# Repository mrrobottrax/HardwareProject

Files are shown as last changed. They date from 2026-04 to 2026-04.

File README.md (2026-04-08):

# Bomb Defusal Game

Project Members:

Ethan Schledewitz-Edwards 100908840

Andrew Hoult 100866035

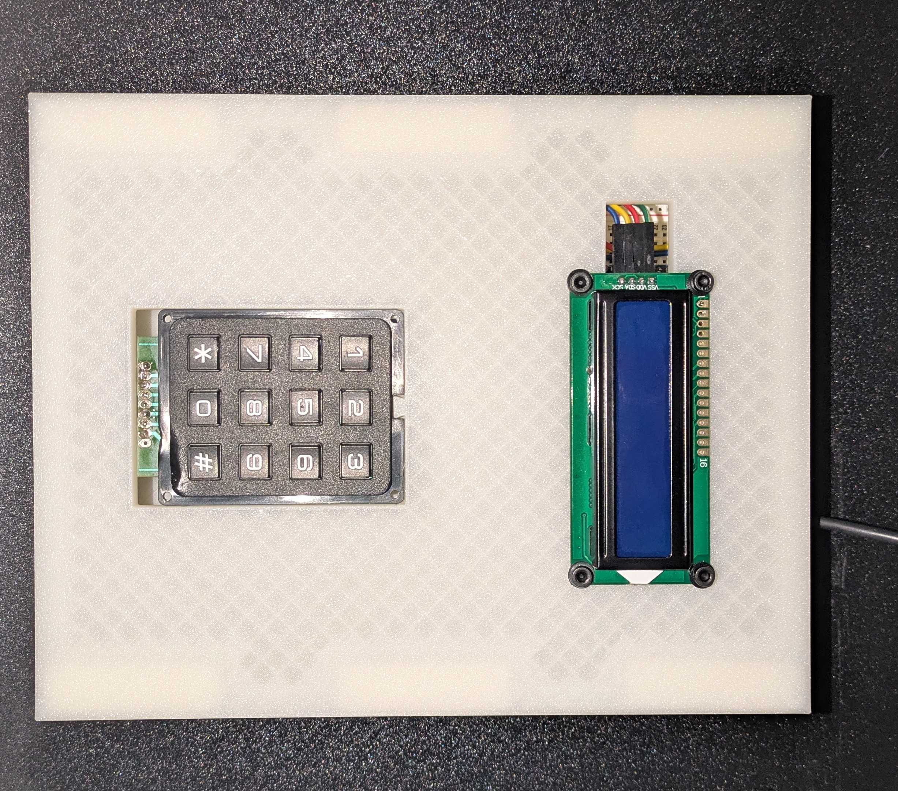
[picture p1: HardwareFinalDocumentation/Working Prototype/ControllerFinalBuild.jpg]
Final build


## Repository Structure

Documentation is stored in HardwareFinalDocumentation/, source code is stored in SourceCode/.

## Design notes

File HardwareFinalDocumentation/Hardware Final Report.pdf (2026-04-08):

# Developing a Tangible User Interface for Entertainment

Andrew Hoult
Faculty of Business and Information Technology Ontario Tech University
Oshawa, ON, Canada
andrew.hoult@ontariotechu.net

Ethan Schledewitz-Edwards
Faculty of Business and Information Technology Ontario Tech University
Oshawa, ON, Canada
ethan.schledewitzedwars@ontariotechu.net

Abstract—Designing and developing an intuitive Tangible User Interface (TUI) involves many careful considerations. Intuitive operation, comfort in layout, immersive-ness, and responsiveness must be factored into the iterative process. The purpose of this device is to create a “bomb-defusal” controller that leverages physical and design affordances to satisfy these pillars of design. Initial paper prototyping focused on ergonomics and identifiable iconography associated with bombs in media. Later prototypes focused on implementing one component of the controller incrementally. User testing of a prototype reveals that incorporating design and physical affordances into TUI’s results in intuitive systems.
Index Terms—Physical User Interface, Tactile, Tangible User Interface, Intuitive, Affordances
I. Introduction

For a Tangible User Interface (TUI) to be successful, it must be intuitive to operate, comfortable to engage with, immersive, and respond as the user expects. These core pillars are essential when designing immersive gaming hardware that relies on physical interaction as its primary mechanic. This report details the development of a physical “bomb-defusal” controller inspired by the digital game Keep Talking and Nobody Explodes. The project explores how design affordances can be leveraged to create a fun experience that a user can complete without instruction. To solve this problem, the device implements tactile inputs through a matrix keypad and an accelerometer to map digital game logic onto familiar physical interactions. Users are tasked with defusing the bomb by playing through separate game modules using the sensors implemented in the device. [1], [2]

II. Materials and Methods

A. Materials

The core logic of this device is controlled by an ESP32 micro-controller. The ESP32 was chosen for its low cost, processing speed, and compact size. User input is captured via two primary interfaces: a 3x3 matrix keypad and a 3-axis I2C MPU6050 accelerometer. The keypad was chosen for its versatility across multiple games and its association with the design of bombs in media. The accelerometer was integrated to introduce unconventional, motion-based mechanics not typically found in representations of bomb defusal.

Visual feedback is rendered via an HD44780 compatible 1602 LCD over I2C, while audio is output from a DFPlayer Mini communicating with the ESP32 over UART to drive a speaker. The chassis of this device was modeled in Fusion 360 and constructed using 3D-printed PLA, resulting in a lightweight and durable enclosure.

B. Methods

The hardware was developed through an iterative process. Initial cardboard prototyping was used to determine the optimal size of the chassis and the placement of the sensors and actuators. This was followed by a functional prototype where the physical components were validated on a breadboard individually. The final iteration involved migrating the components from a temporary breadboard to the printed chassis, ensuring the controller could withstand being tilted and handled during the accelerometer-based game.

III. Results

The final prototype successfully integrated all hardware modules into a cohesive TUI. User testing confirmed that the ESP32 maintained stable communication with the I2C accelerometer and the UART-driven MP3 speaker. However, testing revealed that the LCD display was highly unstable. When powered over USB, the display’s internal controller would occasionally enter an unrecoverable state until power cycled. A 100μf capacitor was added as an attempt to mitigate this phenomenon, with inconclusive results. Additionally, input latency between the matrix keypad and the display was found during user testing. This latency is attributed to the software and was rectified in future iterations.
User testing focused on intuitiveness and the responsiveness of the keypad interface. Quantitative data from the SUS and NASA-TLX surveys (see Table I and Table II) highlight the device’s ease of use, high task success, and low participant stress, validating the keypad’s design affordances. Unfortunately, due to timing, testing could not be performed with the components housed within the chassis. Additionally, the accelerometer was not utilized in the game used for the test.

IV. Takeaways

The development of this tangible “bomb-defusal” controller confirms that integrating design affordances, such as a keypad, significantly reduced the cognitive load required for immersive gameplay without instruction. This is supported by a mean SUS score of 78.3, indicating “High” usability. However, the identified LCD instability and input latency resulted in some users reporting perceivable inconsistencies in the device. For this device to be successful, these inconsistencies must be alleviated to create an immersive experience. Going forward, the core pillars of intuitive operation, comfort in layout, immersive-ness, and responsiveness must be applied to the rest of the components as they are integrated.

TABLE I
System Usability Scale (SUS) survey responses (N=9).
User | Q1 | Q2 | Q3 | Q4 | Q5 | Q6 | Q7 | Q8 | Q9 | Q10
1 | 4 | 2 | 2 | 1 | 5 | 2 | 5 | 2 | 3 | 2
2 | 3 | 3 | 4 | 2 | 4 | 3 | 4 | 2 | 4 | 2
3 | 3 | 1 | 3 | 1 | 4 | 4 | 5 | 2 | 5 | 1
4 | 2 | 1 | 5 | 1 | 4 | 4 | 5 | 2 | 5 | 2
5 | 4 | 1 | 5 | 1 | 3 | 1 | 5 | 1 | 4 | 2
6 | 5 | 2 | 4 | 3 | 5 | 1 | 5 | 2 | 3 | 2
7 | 4 | 2 | 4 | 1 | 5 | 1 | 4 | 2 | 5 | 3
8 | 4 | 3 | 3 | 1 | 3 | 2 | 4 | 2 | 3 | 1
9 | 3 | 1 | 4 | 1 | 5 | 2 | 5 | 2 | 5 | 1

TABLE II
NASA-TLX workload dimensions measured across 9 participants.
User | Physi-cal | Hur-ried | Suc-cess | Hard Work | Stressed
1 | 1 | 2 | 9 | 3 | 1
2 | 2 | 2 | 7 | 3 | 2
3 | 1 | 4 | 7 | 5 | 3
4 | 1 | 1 | 9 | 6 | 2
5 | 4 | 3 | 10 | 3 | 2
6 | 2 | 8 | 9 | 10 | 1
7 | 1 | 3 | 9 | 1 | 1
8 | 4 | 4 | 8 | 6 | 2
9 | 1 | 1 | 9 | 5 | 2

References

[1] Steel Crate Games, “Keep Talking and Nobody Explodes.” Oct. 2015.
[2] E. Shamilov, N. Gavish, H. Krisher, and E. Horesh, “Tangible user interface,” Engineering Psychology and Cognitive Ergonomics – EPCE 2018, vol. 10906. in Lecture Notes in Computer Science, vol. 10906. Springer, Cham, Switzerland, pp. 393–402, 2018. doi: 10.1007/978-3-319-91122-9_38. (https://doi.org/10.1007/978-3-319-91122-9_38)

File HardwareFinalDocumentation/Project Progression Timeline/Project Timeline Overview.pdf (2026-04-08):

### Project Timeline Overview

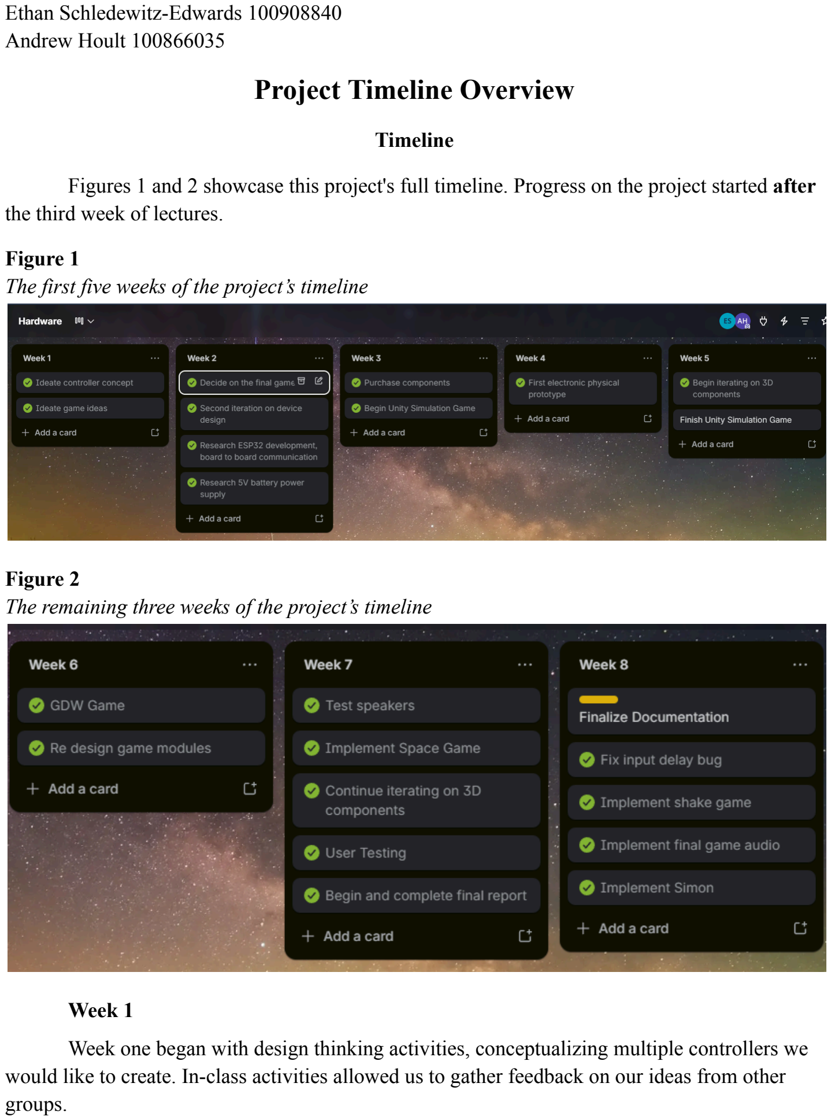
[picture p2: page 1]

Ethan Schledewitz-Edwards 100908840 Andrew Hoult 100866035

Timeline

Figures 1 and 2 showcase this project's full timeline. Progress on the project started after the third week of lectures.

Figure 1
The first five weeks of the project’s timeline

Figure 2
The remaining three weeks of the project’s timeline

Week 1
Week one began with design thinking activities, conceptualizing multiple controllers we would like to create. In-class activities allowed us to gather feedback on our ideas from other groups.

Week 2
Based on our findings in week one, the final concept for our controller was selected and iterated on. The group we consulted the week prior recommended that we include unconventional input methods into our controller to create an element of surprise. Based on the finalized concept, research was conducted to determine which electronic components and materials we needed to purchase to build the controller.
Week 3
Based on the research from the previous week, electronic components were purchased from Amazon. Additionally, a Unity-based simulation of the project began development. The simulation would have allowed us to test the flow of game modules and how they would behave. Week 4
Unfortunately, due to a heavy course load, the Unity prototype was canceled as we deemed it unfeasible. However, the parts ordered the previous week were arriving. Using these components, the initial physical electronic prototyping began using a breadboard.
Week 5
As previously mentioned, the digital Unity prototype had been canceled in week 4. However, in week 5, 3D components were beginning to be iterated on using Fusion 360. These designs focused on housing for the individual components. This week included housing for the Keypad, LCD, and breadboard.

Week 6

Week six mostly focused on improving our GDW game before Milestone 3. However, programming for the controller prototype began, LCD issues were rectified, and an LCD interface was created.

Week 7

The LCD issues are somewhat resolved, the first game is complete, all components are integrated and functioning, and an API for each component has been created. User testing is conducted in the game lab. The final report is written and completed using the data gathered from the user testing.

Week 8

Minor bugs were fixed, and all game modules and code were completed before Tuesday (LevelUp Convention). Finally, the project was submitted on Wednesday morning.

Work Breakdown

Andrew: Assembled electronics, 3D printed parts and iterated design, programmed microcontroller games.

Ethan: I worked on the concept, design, canceled Unity Prototype, some 3D component designs, and user testing of the project along with Andrew. I also handled all of the technical documentation.

Overall, we feel that the workload was evenly distributed between us, 50% each.

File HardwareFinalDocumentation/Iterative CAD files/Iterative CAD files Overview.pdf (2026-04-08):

Ethan Schledewitz-Edwards 100908840 Andrew Hoult 100866035

### Iterative CAD files Overview

Video Demonstration

Exploded View Video: https://youtu.be/3uYHuE0vSzA

Electronic Schematics

Multiple changes to the scope of the project were made for the electronic components. Initially, the components were selected to facilitate 5 unique games, with dedicated sensors and actuators for most. Since the project focused primarily on game design, its scope was initially quite large. However, as the final deadline approached, technical feasibility was assessed, and costs were factored in; two final sensors and actuators were chosen. Figure 1 illustrates the initial schematic used to construct the final prototype.
The first sensor included in the final prototype is the 3x3 matrix keypad. The keypad was chosen for numerous reasons. First, the keypad allows the concept of the controller to meet the users' expectations of a “bomb-defusal” game. As discussed in the final report, bombs in popular media often depict bombs with a keypad on the front. By using a keypad, the device could leverage established design conventions to communicate the purpose of the device more easily. Next, the keypad was favoured for the number of buttons on the keypad, which supports a wide variety of games.
The second sensor included in the final prototype of this controller was an accelerometer. Because this project focuses on “unconventional” gameplay not commonly associated with bomb-defusal, an accelerometer was selected to surprise the user. The accelerometer is used in the “shake” game, where the user must shake the controller vigorously to increase a progress bar. Next, the first actuator chosen for the controller was the I2C LCD. For the same reason mentioned for the matrix keypad, the LCD aids the controller in bridging the user's mental gap between bombs in media and this controller. The LCD display also facilitates multiple games, making it a versatile choice for this project.
Lastly, the second actuator chosen for this project is the speaker. The speaker allows the controller to play a variety of sounds conveying its state to the user. Sounds are played through the speaker from a micro SD bus, and range from conventional ominous bomb ticking sounds to more unfamiliar sounds. For reasons previously mentioned, combining both conventional bomb iconography with unconventional new elements unique to this controller creates a sense of surprise in the user.

Figure 1
An electronic schematic made in Tinkercad

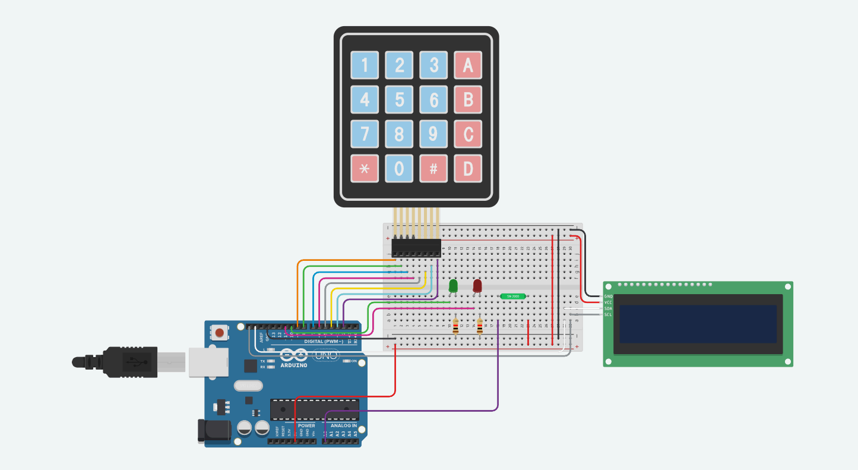
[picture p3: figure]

Note. This schematic is missing an accelerometer and a speaker. These omissions were made because the scope of the project had not been finalized.

3D Assembly

Blueprints/Drawings

The following two drawings were made using Fusion 360's drafting tools. Custom housing for each component of this controller was designed and iterated on separately. Each iteration brought the housing closer to the required dimensions of each component. For example, iterations changed the size of screw holes.

Figure 2 is the blueprint for the Lid of the controller. On the lid is the housing for the LCD display and the Keyboard. Once both housing designs were finalized, the two components were attached to the Lid of the device.

Figure 2
A technical drawing of the Lid

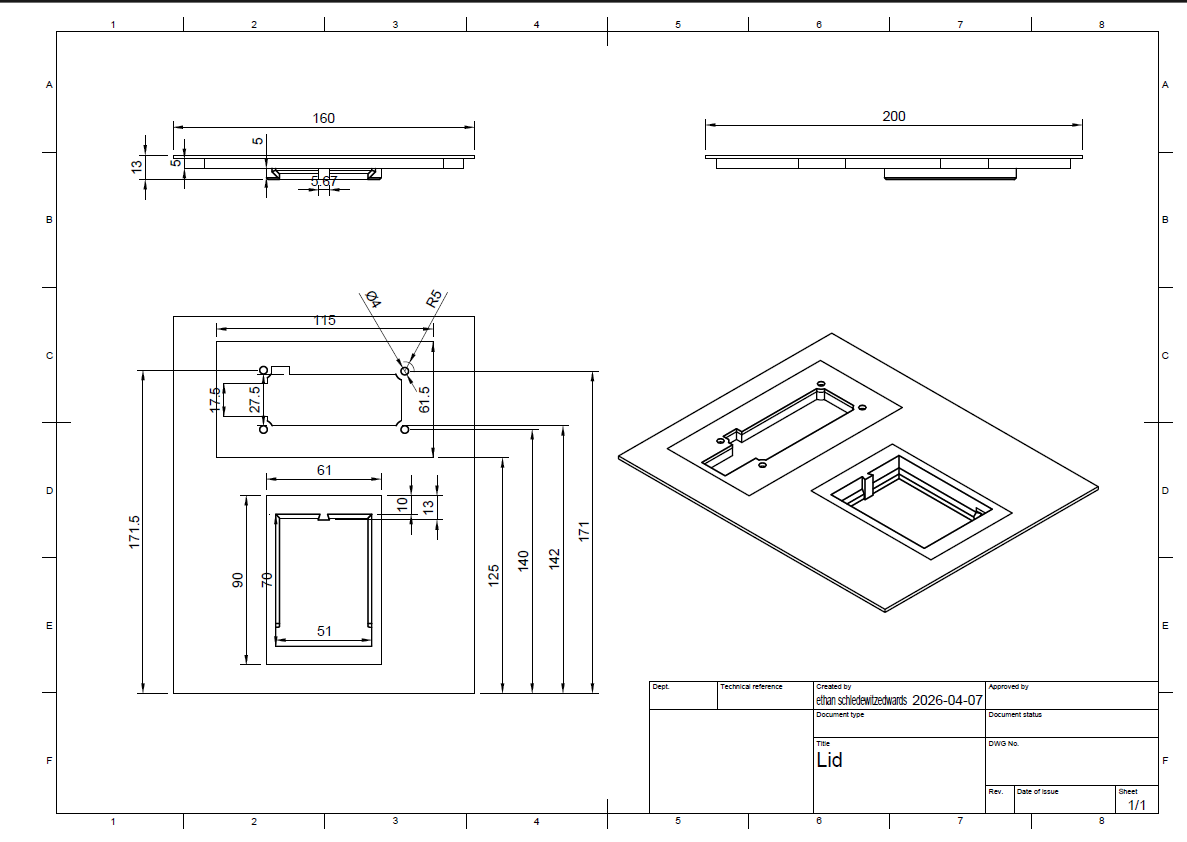
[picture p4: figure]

Figure 3 is the blueprint for the Chassis of the controller. The Chassis includes six magnets to fasten it to the bottom of the Lid. The chassis features a custom mount for the breadboard, ESP32, and speaker. The three custom mounts were iterated on separately and added to the Chassis once they were finalized.

Figure 3
A technical drawing of the Chassis

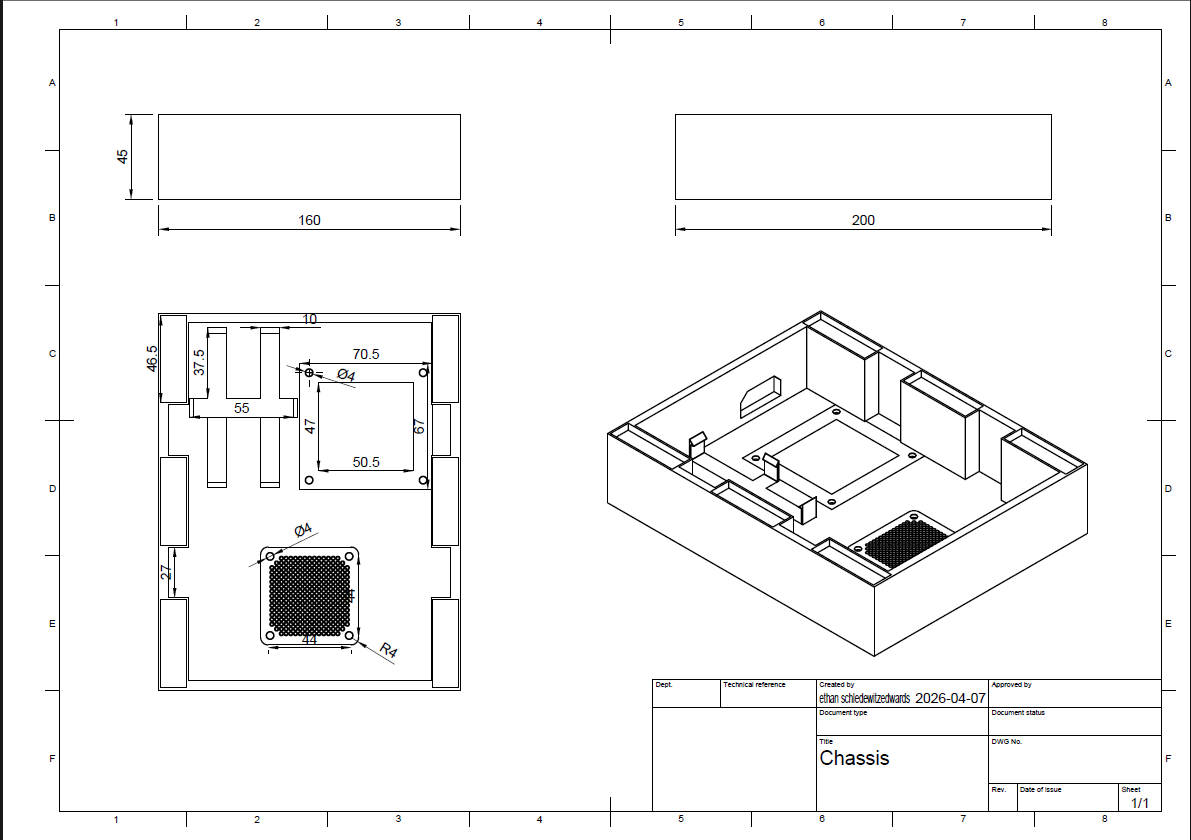
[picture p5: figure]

Exploded View

Figure 3 showcases the exploded view of our controller. The image was captured from our “Controller Exploded View” video, which was rendered using Fusion 360’s animation tools.

Figure 3
A screenshot of the Exploded View from the rendered video

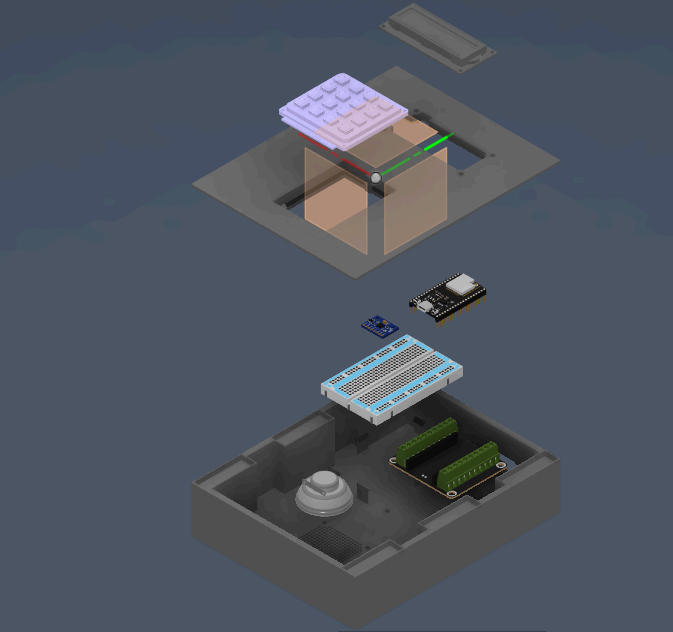
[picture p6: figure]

Approach on Iteration

To ensure that all the electronic components and wires fit neatly within our controller's exterior, careful measurements were taken for each part using calipers. Each measurement also detailed recommended clearance for wiring, ensuring the shell could contain absolutely everything. For example, Figure 4 illustrates the measurements taken for the 3x3 Matrix Keypad with a suggested clearance for wiring to run 3mm below the component.

Figure 4
Measurements for the keypad, taken using calipers

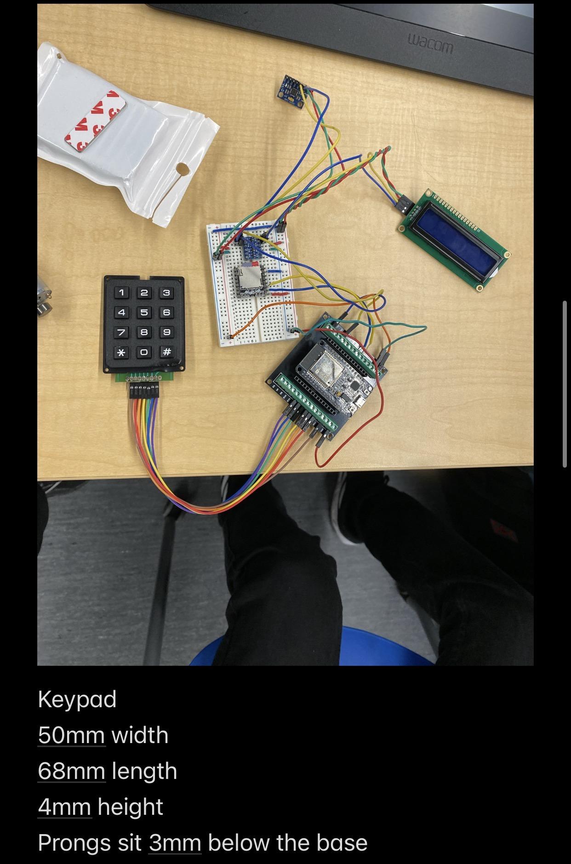
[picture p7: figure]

Using these measurements, individual housing for each component was prototyped using Fusion 360. For instance, Figure 5 showcases multiple iterations of housing designed specifically for the LCD screen. Figure 6 highlights multiple iterations for the Keypad and Speaker housing.

Figure 5
Iterations on the housing for the LCD screen

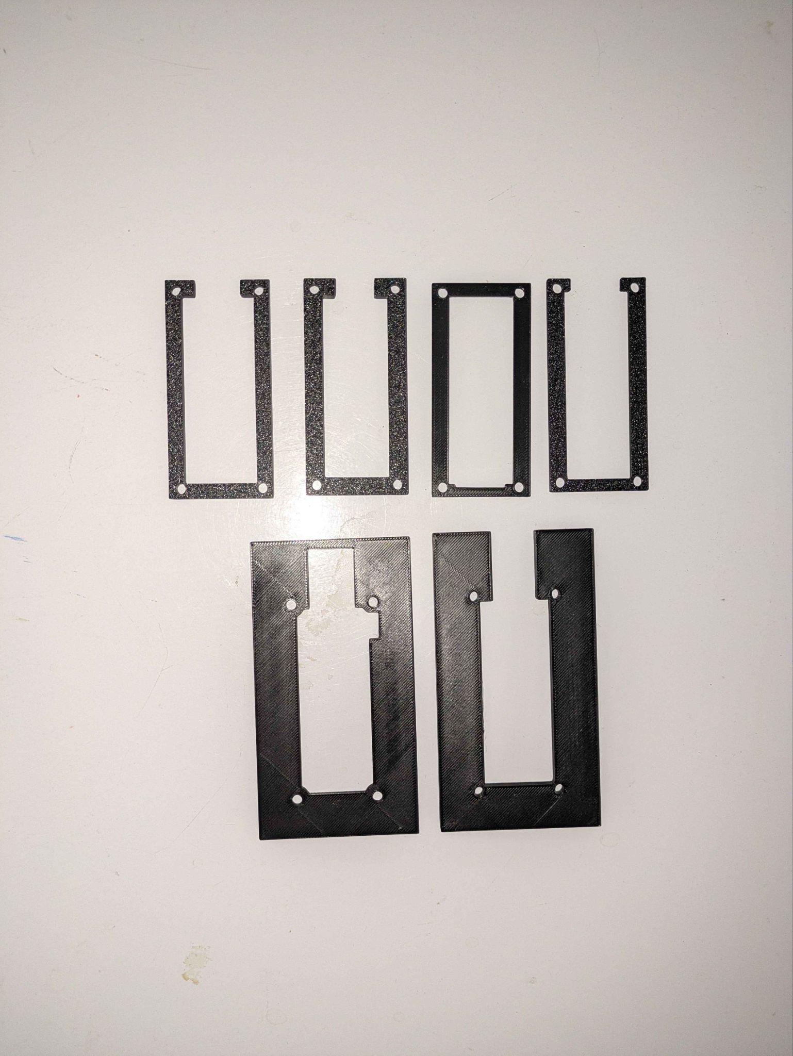
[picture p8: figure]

Figure 6
Iterations on the housing for the keypad, speaker, and breadboard

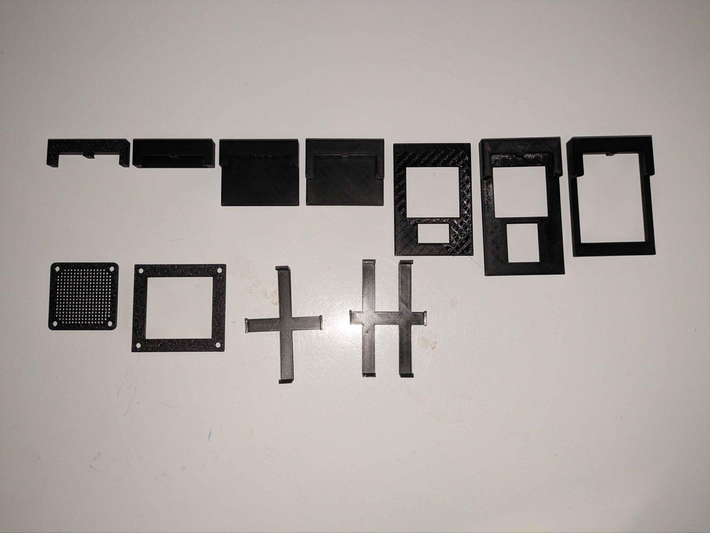
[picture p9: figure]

Note. The top row of prototypes is solely for the Keypad, the bottom row features two iterations for the speaker housing, and three iterations for the breadboard housing.
The design of the housing for each component was iterated on extensively, ensuring it fit each component optimally. Once each individual component had housing designed for it, all components were combined into the design for the final Chassis and Lid of this controller prototype. Much like the housing for the individual components, both the Chassis and Lid underwent multiple iterations to ensure everything fit nicely.

Bill of Materials

After the design of the Lid and Chassis of the controller was finalized, the Bill of Materials visualized in Figure 7 was created using Fusion 360’s drawing tools.

Figure 7
The final Bill of Materials

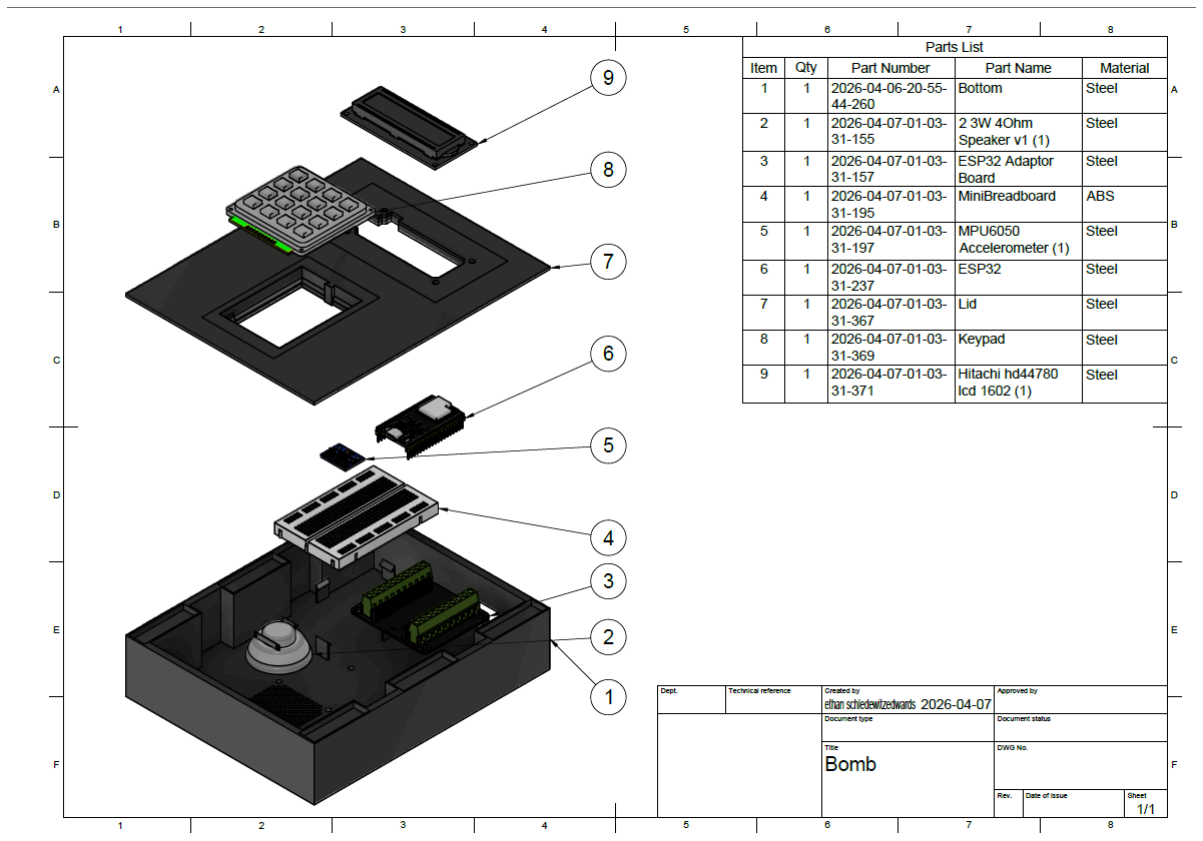
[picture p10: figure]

Note. Some of the models used to represent the electronic components are incorrect and were used as approximations for the exploded view and bill of materials. The incorrect components are the matrix keypad and LCD screen.

References

[LCD]
https://grabcad.com/library/hitachi-hd44780-lcd-1602-1

[ESP32]
https://grabcad.com/library/esp32-devkit-32u-with-external-antenna-and-3-types-of-adapter-boar ds-1 (https://grabcad.com/library/esp32-devkit-32u-with-external-antenna-and-3-types-of-adapter-boards-1)

[Breadboard]

https://grabcad.com/library/minibreadboard-2

[Accelerometer]
https://grabcad.com/library/mpu6050-accelerometer-module-2

[Speaker]
https://grabcad.com/library/3w-4ohm-speaker-1

[Keypad]
https://grabcad.com/library/4x4-button-keypad-matrix

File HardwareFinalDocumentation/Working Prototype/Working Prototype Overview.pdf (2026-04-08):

Ethan Schledewitz-Edwards 100908840 Andrew Hoult 100866035

### Working Prototype Overview

Video Demonstration

Working Prototype Video Demonstration 1: https://youtu.be/9d6GbXNmM6Y Working Prototype Video Demonstration 2: https://youtu.be/H2iKPrMXN8s

Electronics Integration

The two videos provided above outline the integration of the electronics in this controller prototype comprehensively. Figures 1 and 2 visualize the controller showcased in the videos.

Figure 1
An image of the exterior of the controller prototype

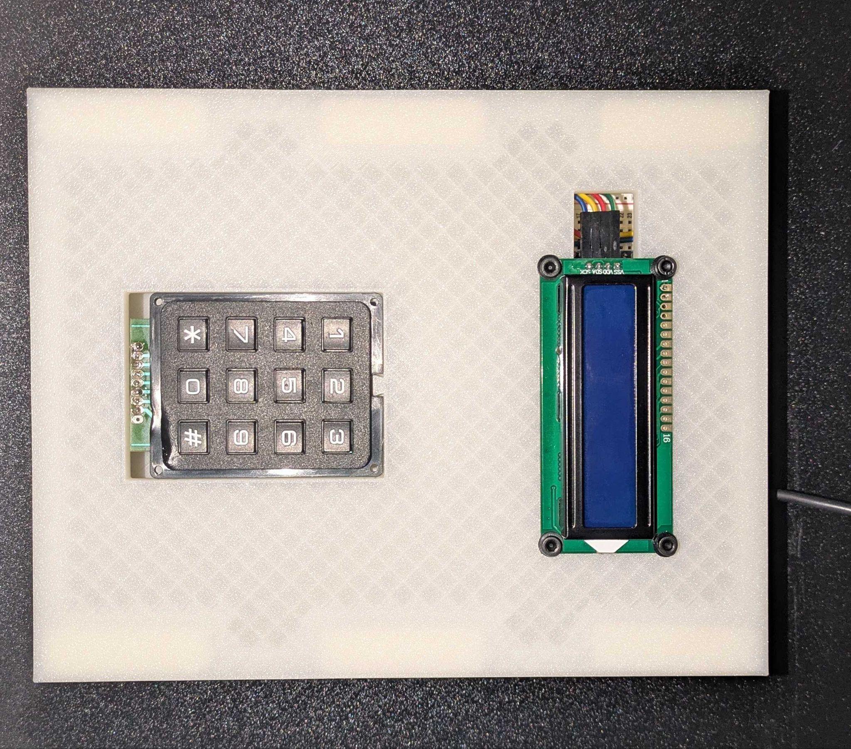
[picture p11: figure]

Figure 2
An image of the interior of the controller prototype

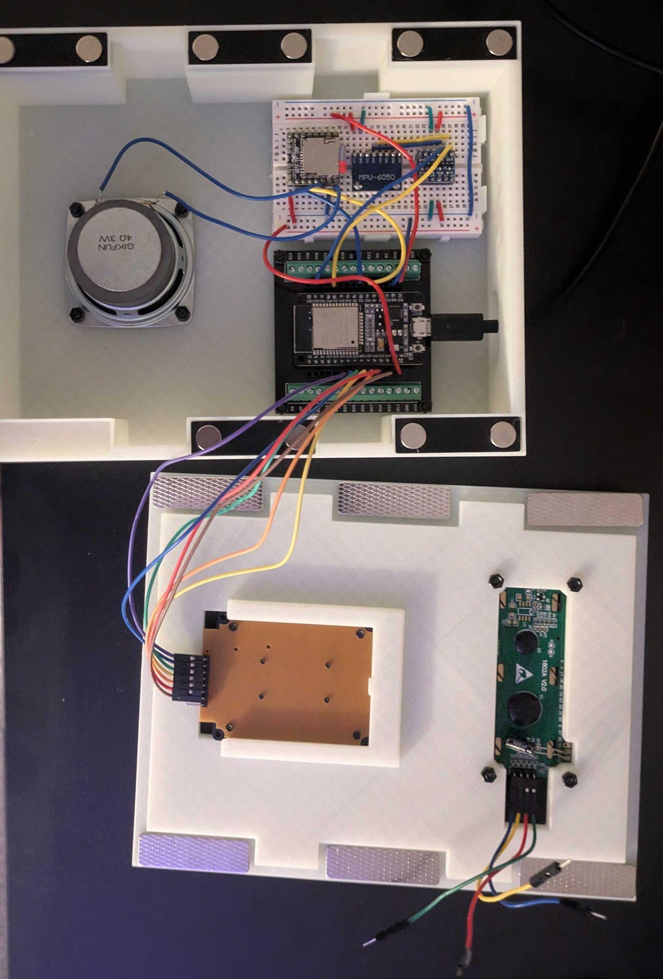
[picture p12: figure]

Bill of Materials

After the design of the Lid and Chassis of the controller was finalized, the Bill of Materials visualized in Figure 3 was created using Fusion 360’s drawing tools.

Figure 3
The final Bill of Materials

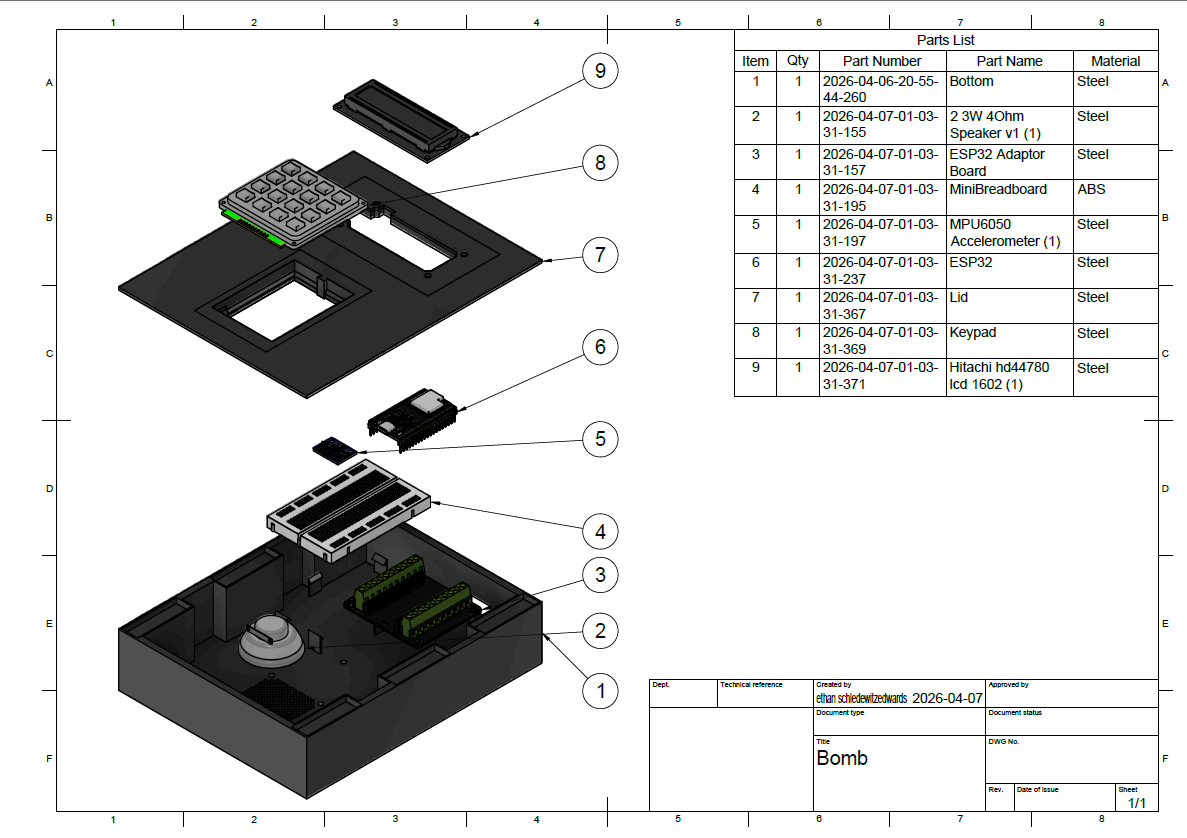
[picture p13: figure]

Note. Some of the models used to represent the electronic components are incorrect and were used as approximations for the exploded view and bill of materials. The incorrect components are the matrix keypad and LCD screen.

References

[LCD]
https://grabcad.com/library/hitachi-hd44780-lcd-1602-1

[ESP32]
https://grabcad.com/library/esp32-devkit-32u-with-external-antenna-and-3-types-of-adapter-boar ds-1 (https://grabcad.com/library/esp32-devkit-32u-with-external-antenna-and-3-types-of-adapter-boards-1)

[Breadboard]
https://grabcad.com/library/minibreadboard-2

[Accelerometer]
https://grabcad.com/library/mpu6050-accelerometer-module-2

[Speaker]
https://grabcad.com/library/3w-4ohm-speaker-1

[Keypad]
https://grabcad.com/library/4x4-button-keypad-matrix

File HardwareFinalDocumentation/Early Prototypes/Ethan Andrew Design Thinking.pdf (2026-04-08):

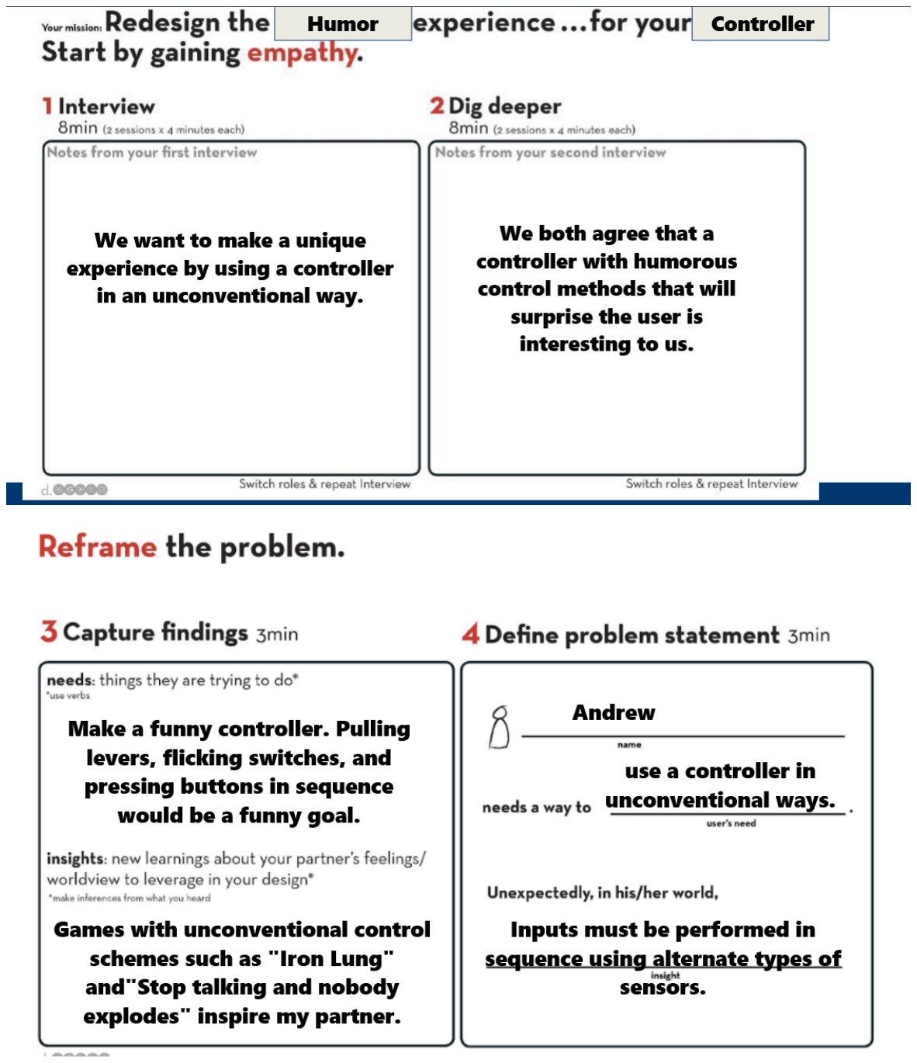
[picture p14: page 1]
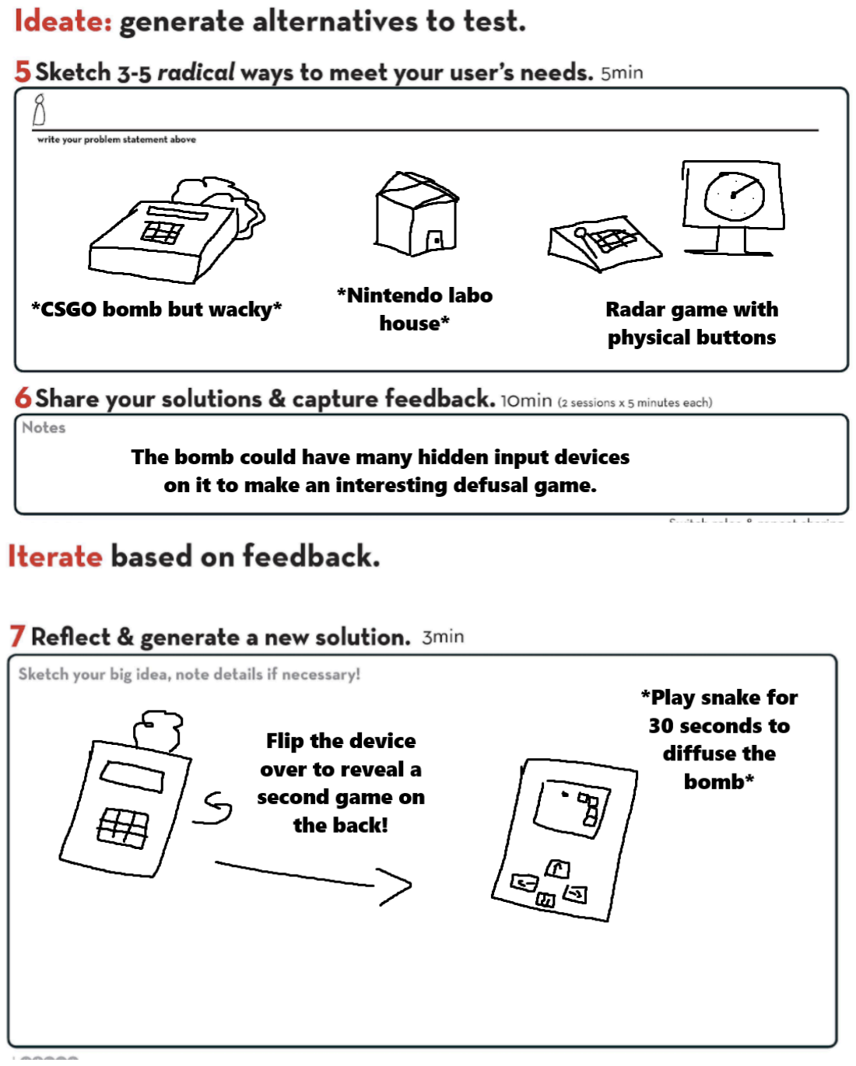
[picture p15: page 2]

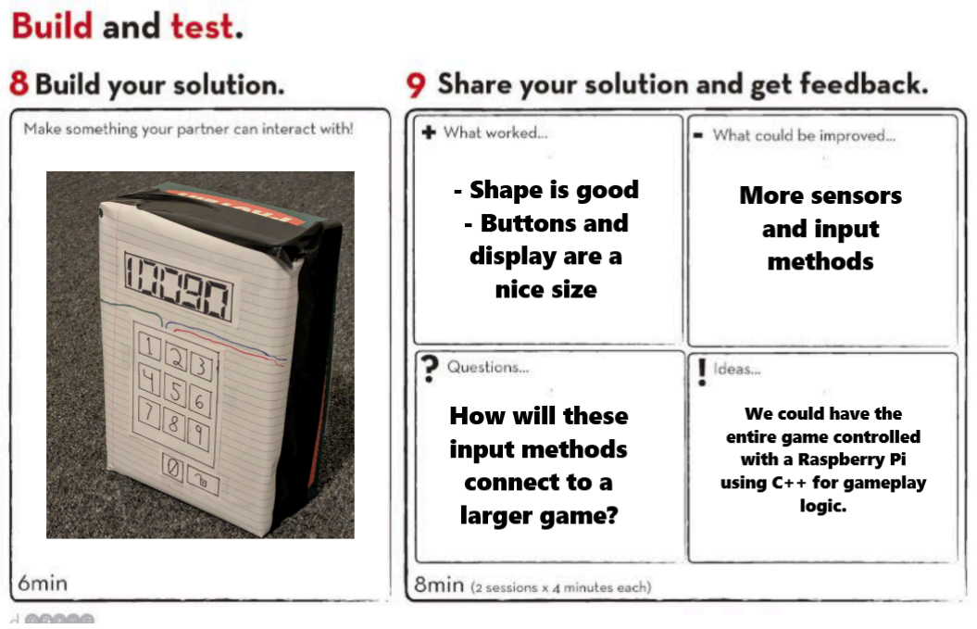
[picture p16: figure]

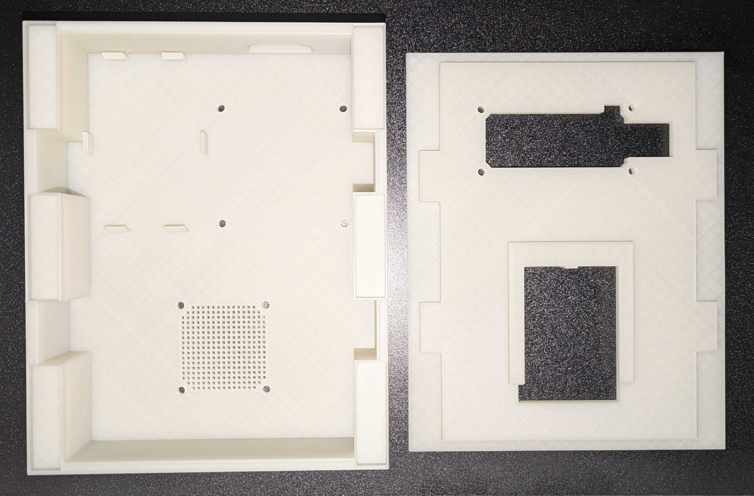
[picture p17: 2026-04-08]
HardwareFinalDocumentation/Iterative CAD files/FinalyChasisAndLid.jpg

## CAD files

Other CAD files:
HardwareFinalDocumentation/Early Prototypes/HardwareController.blend
HardwareFinalDocumentation/FInalControllerPrototype.f3z

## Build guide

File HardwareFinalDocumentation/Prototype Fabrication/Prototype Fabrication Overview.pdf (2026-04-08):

Ethan Schledewitz-Edwards 100908840 Andrew Hoult 100866035

### Prototype Fabrication Overview

Video Demonstration

Lid Slicer Video: https://youtu.be/1y99QEnaCtU
Chassis Slicer Video: https://youtu.be/KqiIBcV46DE Timelapse of Lid print: https://youtu.be/cRQq90OvXEM Timelapse of Chassis print: https://youtu.be/emaSV7wItIM

Materials Chosen

Generic PLA was chosen for 3D printing the Lid and chassis of our controller. The print was done using a Bambu Lab P1S.

Printing Time

Printing the Lid took two hours and nine minutes, as shown in Figure 1. Next, printing the chassis took five hours and twenty minutes, as shown in Figure 2. In total, printing both housing pieces for our controller took seven hours and twenty-nine minutes.

Figure 1
Time to print the lid of the device

Figure 2
Time to print the chassis of the device

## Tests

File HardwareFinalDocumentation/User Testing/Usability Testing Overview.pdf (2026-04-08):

Ethan Schledewitz-Edwards 100908840 Andrew Hoult 100866035

### User Testing Overview

Introduction

The user testing conducted for our controller prototype involved nine participants. Each participant was questioned on their background, SUS, and NASA TLX. Since this project is a group of two, eight total participants were required. The user testing was conducted in the Game Lab and only included one game. The sensor and actuator used for the test were the 3x3 matrix keypad and the I2C LCD. Due to the project running behind schedule due to other academic responsibilities, only one game could be tested using the sensor (the keypad) and actuator (the LCD).
Key takeaways

The final report included with this project fully details our “key takeaways” from the user testing. To summarize these points:

- The prototype controller was simple to use
- Users found the prototype comfortable to interact with the
- Users did not require much assistance to operate the controller prototype
- Users reported inconsistencies with the controller.

A spreadsheet containing the results from the user testing is included with this document. Based on observations, a majority of the friction experienced by the participants stemmed from the LCD screen inexplicably disconnecting temporarily. This discrepancy was lessened by integrating a capacitor into the wiring in response. Despite these inconsistencies, users found the experience intuitive.

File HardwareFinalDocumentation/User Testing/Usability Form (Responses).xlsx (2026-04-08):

Timestamp | What is your gender? | What is your age? | What is your background | Do you have any experience with similar systems? | I think that I would like to use this system frequently. | I found the system unnecessarily complex. | I thought the system was easy to use. | I think that I would need the support of a technical person to be able to use this system. | I found the various functions in this system were well integrated. | I thought there was too much inconsistency in this system | I would imagine that most people would learn to use this system very quickly. | I found the system very cumbersome to use. | I felt very confident using the system. | I needed to learn a lot of things before I could get going with this system. | How physically demanding was the task? | How hurried or rushed was the pace of the task? | How successful were you in accomplishing what you were asked to do? | How hard did you have to work to achieve your level of performance? | How insecure, discourage, irritated, stressed, and annoyed were you?
2026-04-02 19:09 | Male | 24 | GDIW | I’ve used num pad before | 4 | 2 | 2 | 1 | 5 | 2 | 5 | 2 | 3 | 2 | 1 | 2 | 9 | 3 | 1
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

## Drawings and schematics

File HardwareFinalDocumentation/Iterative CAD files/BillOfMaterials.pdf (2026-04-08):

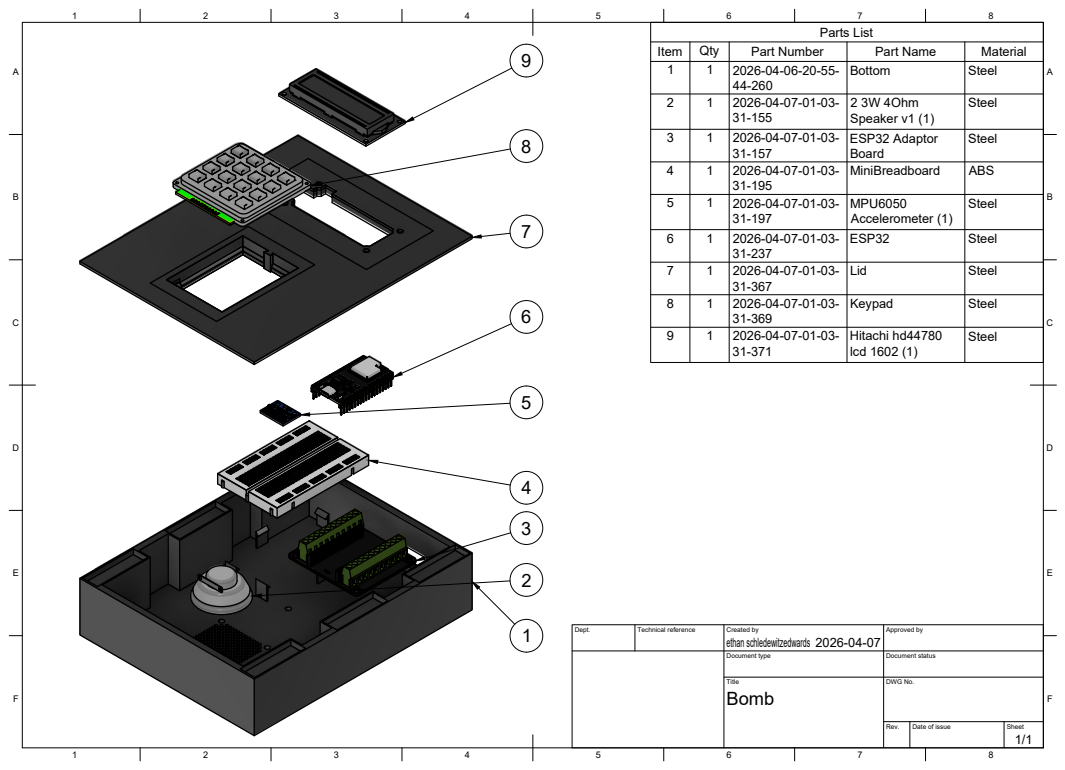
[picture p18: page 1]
8 BCDEF; ABCDEF; Title; DWG No.; Rev.; Date of issue; Sheet; Parts List; Steel 213456789

Item | Qty 1 | 2026-04-06-20-55-Part Number | Part Name | Material 1
1 | 2026-04-07-01-03-44-260 | Bottom | Steel 2

1 | 2026-04-07-01-03-31-155 | 2 3W 4Ohm Speaker v1 (1) | Steel 3

1 | 2026-04-07-01-03-31-157 | ESP32 Adaptor Board | Steel 4

1 | 2026-04-07-01-03-31-195 | MiniBreadboard | ABS 5

1 | 2026-04-07-01-03-31-197 | MPU6050 Accelerometer (1) | Steel 6

1 | 2026-04-07-01-03-31-237 | ESP32 | Steel 7

1 | 2026-04-07-01-03-31-367 | Lid | Steel 8

1 | 2026-04-07-01-03-31-369 | Keypad | Steel 9

31-371 | Hitachi hd44780 lcd 1602 (1)

Dept. | Technical reference | Created by ethan schledewitzedwards 2026-04-07 | Approved by

Document type | Document status

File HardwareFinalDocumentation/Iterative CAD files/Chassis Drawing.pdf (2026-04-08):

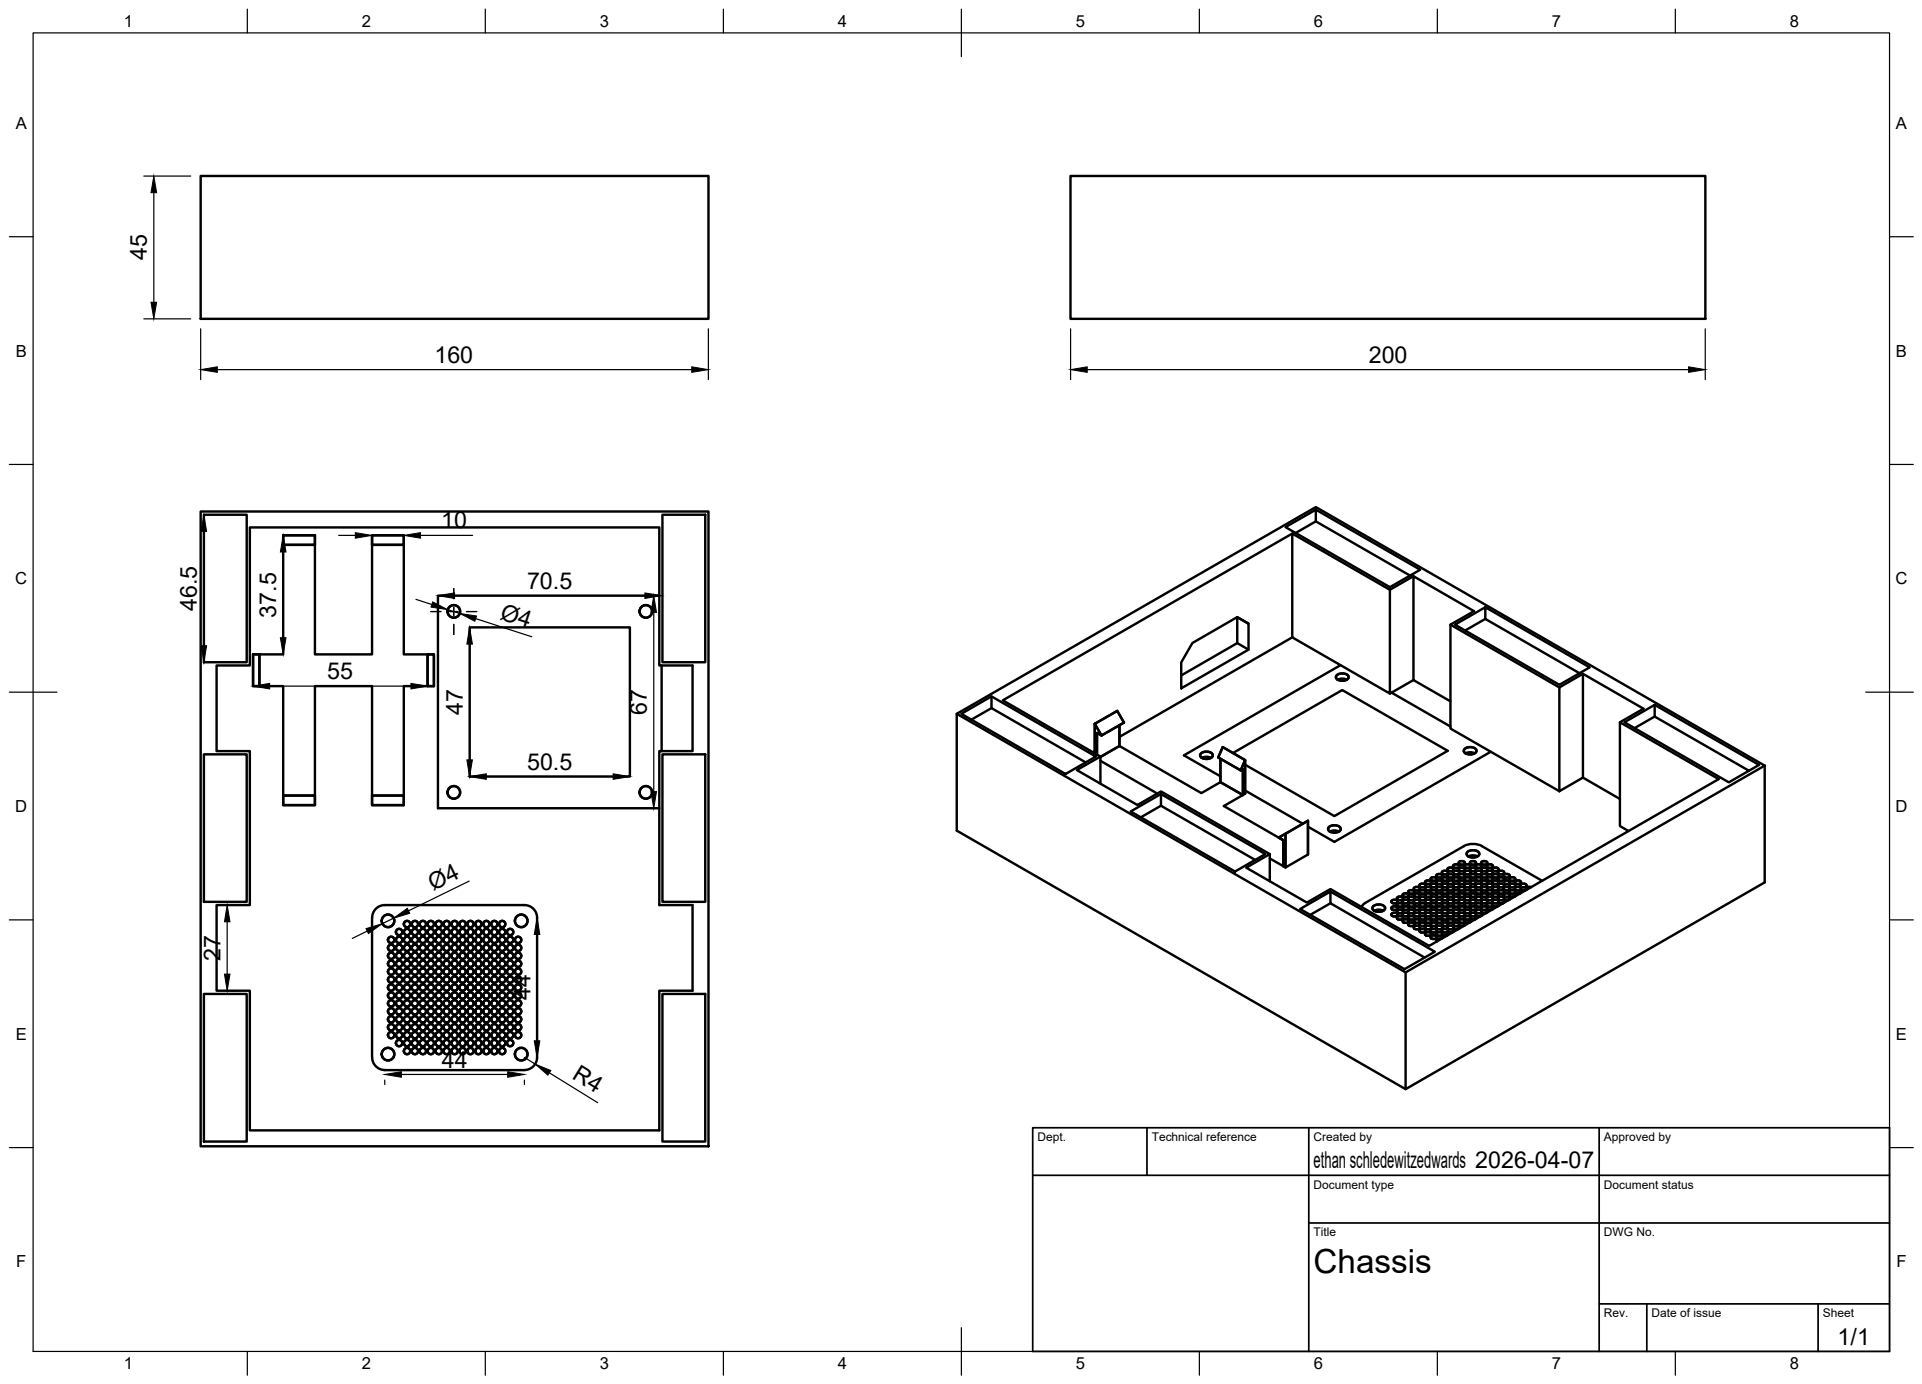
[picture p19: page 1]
Title; DWG No.; Rev.; Date of issue; Sheet

Dept. | Technical reference | Created by ethan schledewitzedwards 2026-04-07 | Approved by

Document type | Document status

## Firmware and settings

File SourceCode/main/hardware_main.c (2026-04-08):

#include <stdio.h>
#include <inttypes.h>
#include <freertos/FreeRTOS.h>
#include <driver/i2c_master.h>

#include "display.h"
#include "input.h"
#include "audio.h"
#include "accelerometer.h"
#include "meta_logic.h"

#include "space_game.h"
#include "shake_game.h"
#include "simon_game.h"
#include "test_task.h"

#define I2C_PORT 0x00

void app_main(void)
{
    vTaskDelay(1000 / portTICK_PERIOD_MS);

    printf("Starting I2C on port %i\n", I2C_PORT);

    i2c_master_bus_config_t i2c_mst_config = {
        .clk_source = I2C_CLK_SRC_DEFAULT,
        .i2c_port = I2C_PORT,
        .scl_io_num = 22,
        .sda_io_num = 21,
        .glitch_ignore_cnt = 3,
        .flags.enable_internal_pullup = false,
    };
    i2c_master_bus_handle_t bus_handle;
    ESP_ERROR_CHECK(i2c_new_master_bus(&i2c_mst_config, &bus_handle));

    for (int i = 0; i <= 0x7F; ++i)
    {
        if (i2c_master_probe(bus_handle, i, -1) == ESP_OK)
        {
            printf("Found I2C %i\n", i);
        }
    }

    printf("Starting Game...\n");

    ESP_ERROR_CHECK(input_init());
    ESP_ERROR_CHECK(display_init(I2C_PORT));
    ESP_ERROR_CHECK(audio_init());
    ESP_ERROR_CHECK(accel_init(I2C_PORT));

    TaskHandle_t display_task_handle;
    if (xTaskCreatePinnedToCore(display_task, "Display Task", 4096, NULL, 1, &display_task_handle, 0) != pdPASS)
        ESP_ERROR_CHECK(ESP_FAIL);

    TaskHandle_t game_logic_task_handle;
    if (xTaskCreatePinnedToCore(meta_logic_task, "Meta Logic", 4096, NULL, 2, &game_logic_task_handle, 1) != pdPASS)
        ESP_ERROR_CHECK(ESP_FAIL);

    // TaskHandle_t game_logic_task_handle;
    // if (xTaskCreatePinnedToCore(simon_game_task, "Game Test", 4096, NULL, 2, &game_logic_task_handle, 1) != pdPASS)
    //     ESP_ERROR_CHECK(ESP_FAIL);
}

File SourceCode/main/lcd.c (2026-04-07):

#include "lcd.h"

#include "freertos/FreeRTOS.h"

/*

LCD Bits:
PCF8574 Bit 	LCD Function	Description
P0	            RS	            Register Select (0 = Command, 1 = Data)
P1	            R/W	            Read/Write (usually kept 0 for Write)
P2	            EN	            Enable (Strobe to clock data)
P3	            BL	            Backlight Control (1 = On, 0 = Off)
P4	            D4	            Data Bit 4 (High nibble mode)
P5	            D5	            Data Bit 5
P6	            D6	            Data Bit 6
P7	            D7	            Data Bit 7

*/

// https://www.scribd.com/document/564283347/LCD-HD44780-instruction-set

#define DELAY 50
#define TIMEOUT 1000

typedef struct
{
    bool is_address_cg;
    uint8_t mem_address;
    uint8_t shift;

    uint8_t ddram_0[40];
    uint8_t ddram_1[40];
    uint8_t cgram[64];
} lcd_state_t;

typedef struct lcd_t
{
    uint16_t i2c_address;
    i2c_master_bus_handle_t i2c_bus_handle;
    i2c_master_dev_handle_t i2c_dev_handle;

    bool is_device_correct_state;

    lcd_state_t state;
} lcd_t;

static esp_err_t lcd_send_4bit_control(lcd_handle_t lcd_handle, uint8_t data)
{
    const uint8_t BL = 0b1000;
    const uint8_t EN = 0b100;

    if (data > 0xF)
        return ESP_ERR_INVALID_ARG;

    uint8_t l = data << 4;
    l |= BL;

    uint8_t h = l | EN;

    uint8_t d[] = {l, h, l};

    return i2c_master_transmit(lcd_handle->i2c_dev_handle, d, 3, TIMEOUT);
}

static esp_err_t lcd_send_8bit_control(lcd_handle_t lcd_handle, uint8_t data)
{
    const uint8_t BL = 0b1000;
    const uint8_t EN = 0b100;

    uint8_t a_l = data & 0xF0;
    a_l |= BL;

    uint8_t a_h = a_l | EN;

    uint8_t b_l = (data & 0xF) << 4;
    b_l |= BL;

    uint8_t b_h = b_l | EN;

    uint8_t d[] = {a_l, a_h, a_l, b_l, b_h, b_l};

    return i2c_master_transmit(lcd_handle->i2c_dev_handle, d, 6, TIMEOUT);
}

static esp_err_t lcd_send_8bit_data(lcd_handle_t lcd_handle, uint8_t data)
{
    const uint8_t BL = 0b1000;
    const uint8_t EN = 0b100;
    const uint8_t RS = 0b1;

    uint8_t a_l = data & 0xF0;
    a_l |= BL | RS;

    uint8_t a_h = a_l | EN;

    uint8_t b_l = (data & 0xF) << 4;
    b_l |= BL | RS;

    uint8_t b_h = b_l | EN;

    uint8_t d[] = {a_l, a_h, a_l, b_l, b_h, b_l};

    return i2c_master_transmit(lcd_handle->i2c_dev_handle, d, 6, TIMEOUT);
}

static esp_err_t lcd_initialize(lcd_handle_t lcd_handle)
{
    esp_err_t err = ESP_OK;

    err = lcd_send_4bit_control(lcd_handle, 0b0011);
    if (err != ESP_OK)
        return err;
    esp_rom_delay_us(4500);

    err = lcd_send_4bit_control(lcd_handle, 0b0011);
    if (err != ESP_OK)
        return err;
    esp_rom_delay_us(150);

    err = lcd_send_4bit_control(lcd_handle, 0b0011);
    if (err != ESP_OK)
        return err;
    esp_rom_delay_us(DELAY);

    err = lcd_send_4bit_control(lcd_handle, 0b0010);
    if (err != ESP_OK)
        return err;
    esp_rom_delay_us(DELAY);

    err = lcd_send_8bit_control(lcd_handle, 0x28);
    if (err != ESP_OK)
        return err;
    esp_rom_delay_us(DELAY);

    err = lcd_send_8bit_control(lcd_handle, 0x08);
    if (err != ESP_OK)
        return err;
    esp_rom_delay_us(DELAY);

    err = lcd_send_8bit_control(lcd_handle, 0x01);
    if (err != ESP_OK)
        return err;
    esp_rom_delay_us(2000);

    err = lcd_send_8bit_control(lcd_handle, 0x06);
    if (err != ESP_OK)
        return err;
    esp_rom_delay_us(DELAY);

    // display enable
    enum
    {
        display_enable = 0b100,
        cursor = 0b10,
        blink = 0b1,
    };
    uint8_t cmd = 0b1000;

    err = lcd_send_8bit_control(lcd_handle, cmd | display_enable);
    if (err != ESP_OK)
        return err;
    esp_rom_delay_us(DELAY);

    return ESP_OK;
}

static esp_err_t lcd_get_to_correct_state(lcd_handle_t lcd_handle)
{
    lcd_handle->is_device_correct_state = false;

    //ESP_ERROR_CHECK(i2c_master_bus_reset(lcd_handle->i2c_bus_handle));
    
    printf("Getting LCD into state\n");
    
    esp_err_t err;
    err = lcd_initialize(lcd_handle);
    if (err != ESP_OK)
    return err;
    
    printf("LCD Initialized\n");

    // copy ddram
    err = lcd_send_8bit_control(lcd_handle, 0b10000000);
    if (err != ESP_OK)
        return err;
    esp_rom_delay_us(DELAY);

    for (int i = 0; i < 40; ++i)
    {
        err = lcd_send_8bit_data(lcd_handle, lcd_handle->state.ddram_0[i]);
        if (err != ESP_OK)
            return err;
        esp_rom_delay_us(DELAY);
    }

    err = lcd_send_8bit_control(lcd_handle, 0b10000000 | 64);
    if (err != ESP_OK)
        return err;
    esp_rom_delay_us(DELAY);

    for (int i = 0; i < 40; ++i)
    {
        err = lcd_send_8bit_data(lcd_handle, lcd_handle->state.ddram_1[i]);
        if (err != ESP_OK)
            return err;
        esp_rom_delay_us(DELAY);
    }

    // copy cgram
    err = lcd_send_8bit_control(lcd_handle, 0b1000000);
    if (err != ESP_OK)
        return err;
    esp_rom_delay_us(DELAY);

    for (int i = 0; i < sizeof(lcd_handle->state.cgram); ++i)
    {
        err = lcd_send_8bit_data(lcd_handle, lcd_handle->state.cgram[i]);
        if (err != ESP_OK)
            return err;
        esp_rom_delay_us(DELAY);
    }

    // set display shift
    const uint8_t shift = lcd_handle->state.shift;
    if (shift <= 40 - shift)
    {
        for (int i = 0; i < shift; ++i)
        {
            err = lcd_send_8bit_control(lcd_handle, 0b11100);
            if (err != ESP_OK)
                return err;
            esp_rom_delay_us(DELAY);
        }
    }
    else
    {
        for (int i = 0; i < 40 - shift; ++i)
        {
            err = lcd_send_8bit_control(lcd_handle, 0b11000);
            if (err != ESP_OK)
                return err;
            esp_rom_delay_us(DELAY);
        }
    }

    // set address
    if (lcd_handle->state.is_address_cg)
    {
        err = lcd_send_8bit_control(lcd_handle, 0b01000000 | (lcd_handle->state.mem_address & 0b111111));
        if (err != ESP_OK)
            return err;
        esp_rom_delay_us(DELAY);
    }
    else
    {
        err = lcd_send_8bit_control(lcd_handle, 0b10000000 | (lcd_handle->state.mem_address & 0b1111111));
        if (err != ESP_OK)
            return err;
        esp_rom_delay_us(DELAY);
    }

    lcd_handle->is_device_correct_state = true;

    printf("LCD in correct state\n");

    return ESP_OK;
}
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

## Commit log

2026-03-27 Find i2c devices
2026-03-31 Fix display not being fully reset
    [lcd.c]
2026-03-31 Display thread
2026-04-08 Documentation pt.1
    [HardwareController.blend, Usability Form (Responses).xlsx]
2026-04-08 Documentation pt.2
    [FInalControllerPrototype.f3z]
2026-04-08 Add sounds, fix deleted files
    [hardware_main.c]
